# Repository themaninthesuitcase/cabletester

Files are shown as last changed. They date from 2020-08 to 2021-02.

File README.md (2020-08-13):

Arduino 10/16 pin Eurorack IDC Power Cable Tester
=================================================

Forked from [https://github.com/tomarus/cabletester](https://github.com/tomarus/cabletester) with slight modifications to circuit and software (mainly order of connections), and with PCB layout added.

* It only tests (max) 8 wires because of how they're wired in eurorack.
* It can detect shorted cables or faulty/unconnected wires.

This project uses a 128x64 OLED I2C display module with four interface pins: GND, +12V, SCL, and SDA. It is a monochrome display although it is available in a version with a yellow and blue overlay as seen in the photos. Note that the OLED pinout sometimes is GND-VCC-SCL-SDA and sometimes VCC-GND-SCL-SDA. The initial run of boards assumed the latter pinout; the present design has footprints for both.

These modules are available from the "usual suspects" on Amazon, eBay, AliExpress, etc. I have one of [these](https://www.amazon.com/gp/product/B072Q2X2LL) (GND-VCC-SCL-SDA) and one of [these](https://www.amazon.com/gp/product/B07FK8GB8T) (VCC-GND-SCL-SDA). They do *not* seem to be available from any established vendors like Mouser, DigiKey, Tayda, Adafruit, or SparkFun. Please make sure you have a source for the display before proceeding with this project! 

Code uses these libraries:

* https://github.com/adafruit/Adafruit_SSD1306
* https://github.com/adafruit/Adafruit-GFX-Library

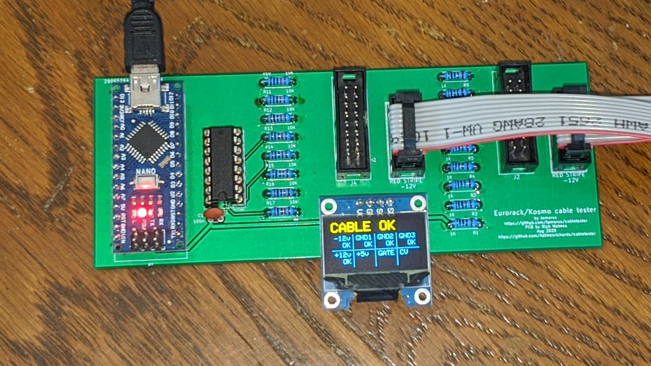
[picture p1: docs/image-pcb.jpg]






# Schematics

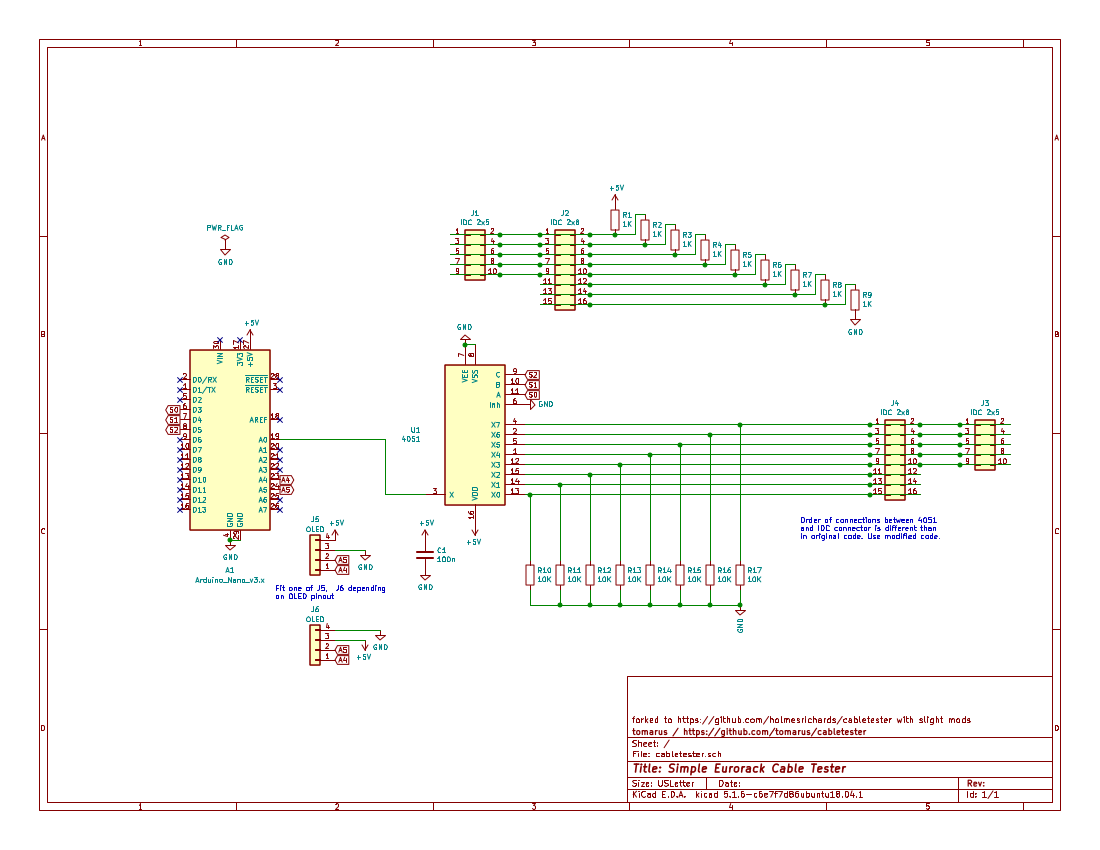
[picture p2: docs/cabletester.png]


# PCB

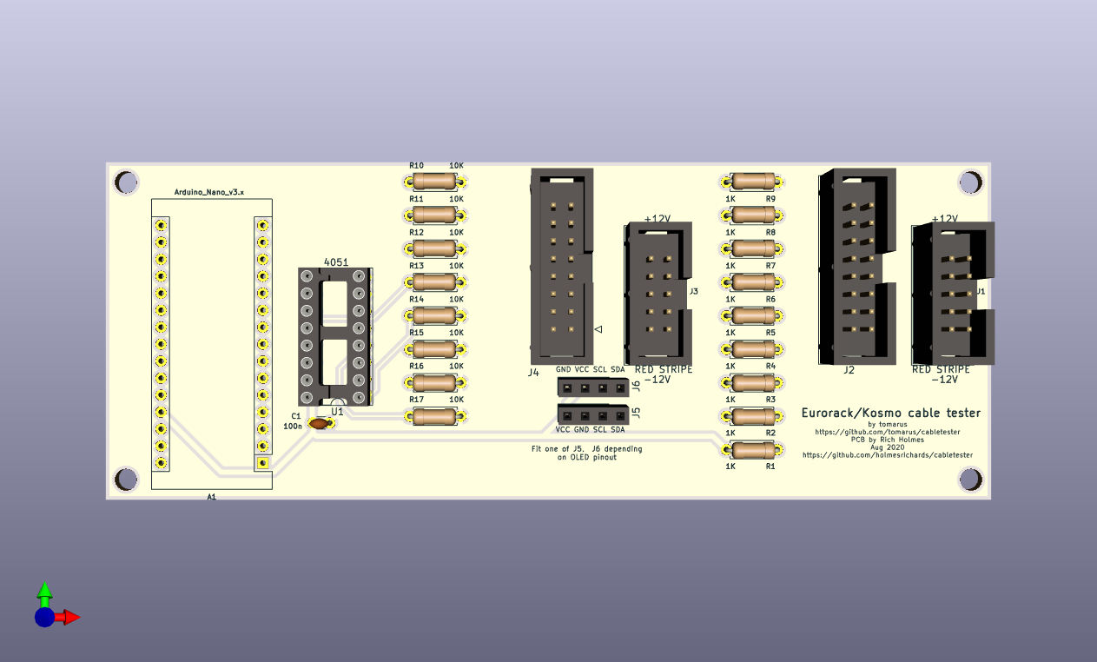
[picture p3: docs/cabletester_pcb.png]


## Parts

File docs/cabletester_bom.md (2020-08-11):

# cabletester BOM

Tue 11 Aug 2020 08:37:09 AM EDT

Generated from schematic by Eeschema 5.1.6-c6e7f7d~86~ubuntu18.04.1

**Component Count:** 26

| Value | Qty | Part | Description | Vendor |
| ----- | --- | ---- | --- | --- |
| A1 | 1 | Arduino_Nano_v3.x | Arduino Nano v3.x | Tayda A-2864 |
| C1 | 1 | 100 nF | Unpolarized capacitor | Tayda A-564 |
| J1, J3 | 2 | IDC 2x5 | Eurorack style 10 pin power header | Tayda A-2939 |
| J2, J4 | 2 | IDC 2x8 | Eurorack style 16 pin power header | Tayda A-2956 |
| J5, J6 | 1 | 4 pin header | 4 pin female 2.54 mm header (fit in one of two locations) | Tayda A-1303 |
| R1, R2, R3, R4, R5, R6, R7, R8, R9 | 9 | 1K | Resistor | Tayda A-2200 |
| R10, R11, R12, R13, R14, R15, R16, R17 | 8 | 10K | Resistor | Tayda A-2203 |
| U1 | 1 | 4051 | Analog Multiplexer 8 to 1 | Tayda A-026 |
| – | 1 | – | 128x64 monochrome I2C OLED module | eBay, AliExpress... |

See [README](../README.md) for notes on OLED module.

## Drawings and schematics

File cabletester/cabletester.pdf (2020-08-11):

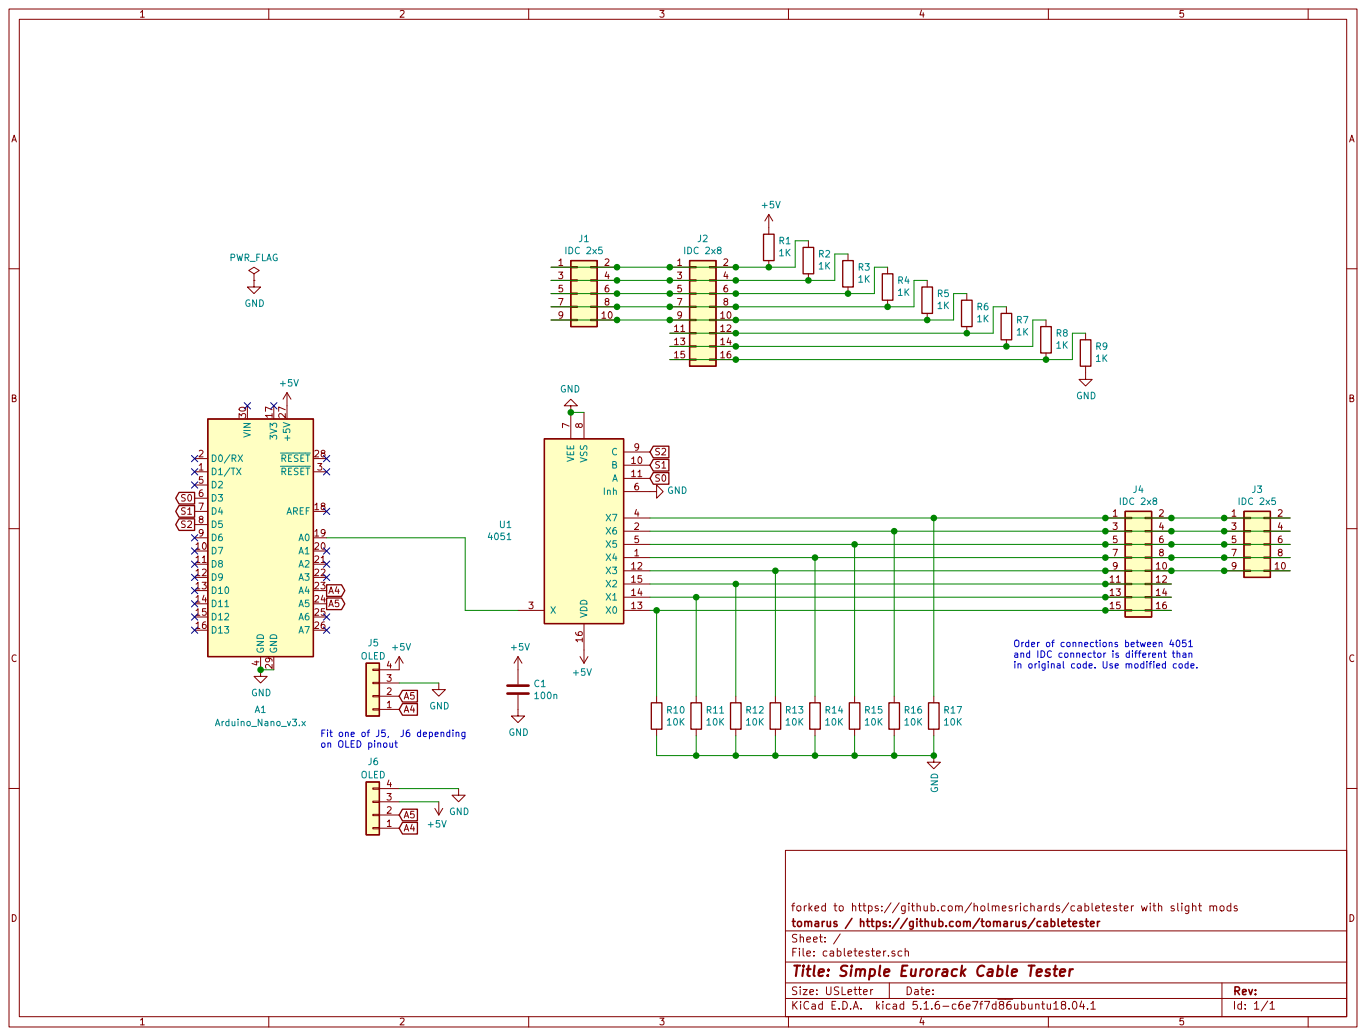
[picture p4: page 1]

and IDC connector is different than
in original code. Use modified code.

Fit one of J5, J6 depending
on OLED pinout

forked to https://github.com/holmesrichards/cabletester with slight mods
Id: 1/1 Title: Simple Eurorack Cable Tester File: cabletester.sch Sheet: / tomarus / https://github.com/tomarus/cabletester

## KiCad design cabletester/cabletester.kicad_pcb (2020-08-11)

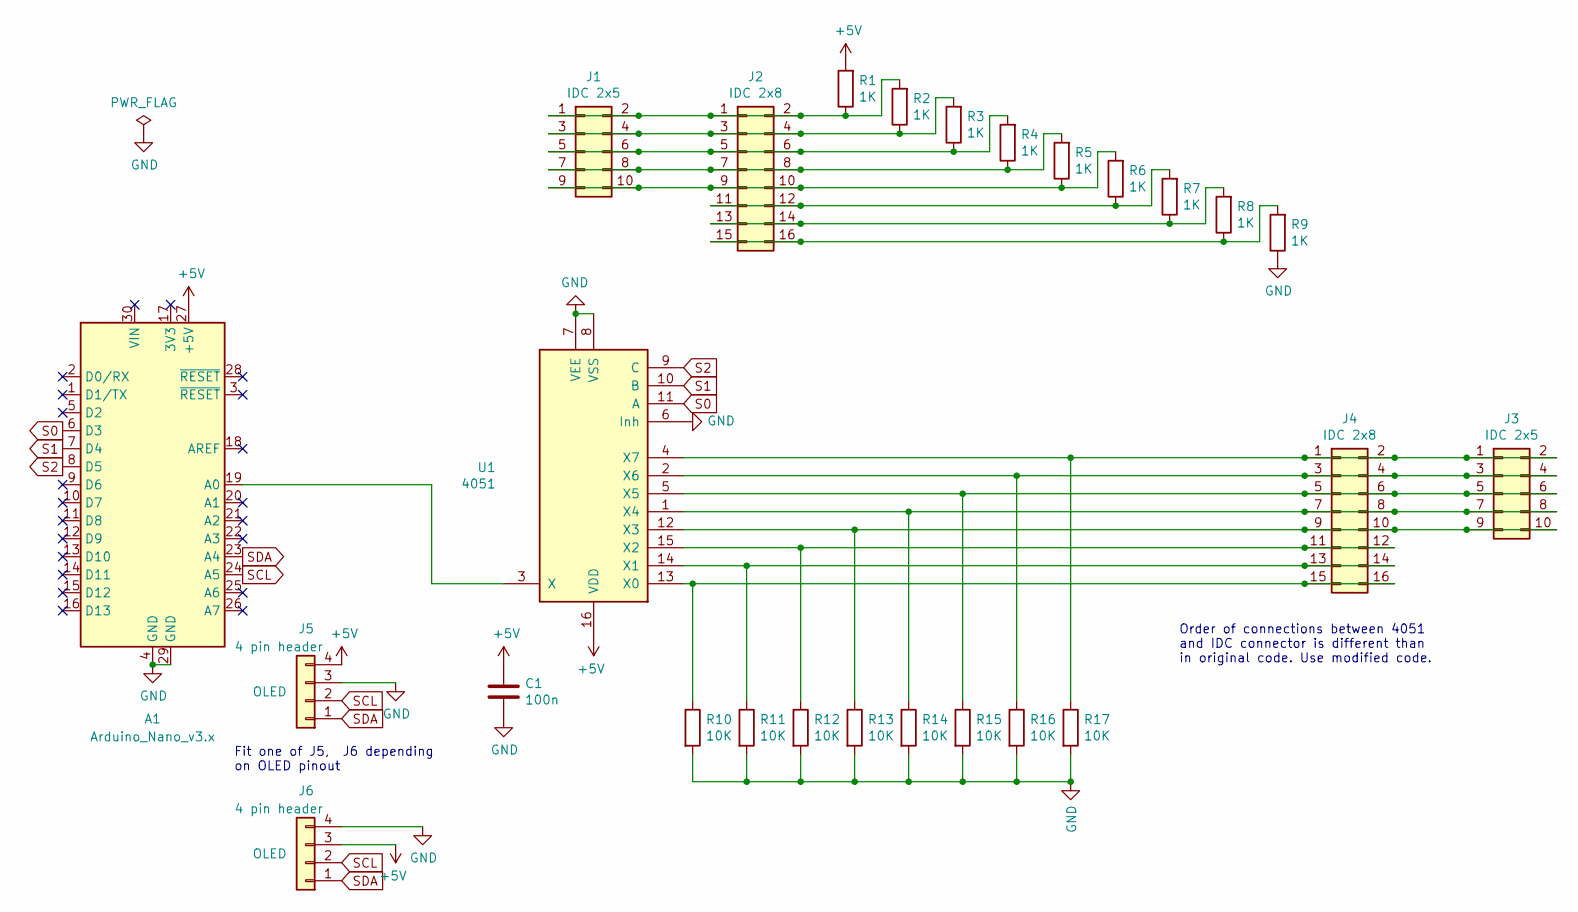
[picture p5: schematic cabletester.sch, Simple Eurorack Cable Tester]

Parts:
A1: Arduino_Nano_v3.x; Arduino_Nano
C1: 100n; C_Disc_D3.0mm_W1.6mm_P2.50mm
J1, J3: IDC 2x5; Power_Header
J2, J4: IDC 2x8; IDC-Header_2x08_P2.54mm_Vertical
J5, J6: 4 pin header; PinSocket_1x04_P2.54mm_Vertical
R1, R2, R3, R4, R5, R6, R7, R8, R9: 1K; R_Axial_DIN0207_L6.3mm_D2.5mm_P7.62mm_Horizontal
R10, R11, R12, R13, R14, R15, R16, R17: 10K; R_Axial_DIN0207_L6.3mm_D2.5mm_P7.62mm_Horizontal
U1: 4051; DIP-16_W7.62mm_Socket_LongPads

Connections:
+5V: A1.27 (+5V), C1.1, J5.4, J6.3, R1.2, U1.16 (VDD)
A4: A1.23 (A4), J5.1, J6.1
A5: A1.24 (A5), J5.2, J6.2
GND: A1.4 (GND), A1.29 (GND), C1.2, J5.3, J6.4, R9.1, R10.2, R11.2, R12.2, R13.2, R14.2, R15.2, R16.2, R17.2, U1.6 (Inh), U1.7 (VEE), U1.8 (VSS)
unnamed: A1.19 (A0), U1.3 (X)
unnamed: J1.1, J1.2, J2.1, J2.2, R1.1, R2.2
unnamed: J1.3, J1.4, J2.3, J2.4, R2.1, R3.2
unnamed: J1.5, J1.6, J2.5, J2.6, R3.1, R4.2
unnamed: J1.7, J1.8, J2.7, J2.8, R4.1, R5.2
unnamed: J1.9, J1.10, J2.9, J2.10, R5.1, R6.2
unnamed: J2.11, J2.12, R6.1, R7.2
unnamed: J2.13, J2.14, R7.1, R8.2
unnamed: J2.15, J2.16, R8.1, R9.2
unnamed: J3.1, J3.2, J4.1, J4.2, R17.1, U1.4 (X7)
unnamed: J3.3, J3.4, J4.3, J4.4, R16.1, U1.2 (X6)
unnamed: J3.5, J3.6, J4.5, J4.6, R15.1, U1.5 (X5)
unnamed: J3.7, J3.8, J4.7, J4.8, R14.1, U1.1 (X4)
unnamed: J3.9, J3.10, J4.9, J4.10, R13.1, U1.12 (X3)
unnamed: J4.11, J4.12, R12.1, U1.15 (X2)
unnamed: J4.13, J4.14, R11.1, U1.14 (X1)
unnamed: J4.15, J4.16, R10.1, U1.13 (X0)
S0: A1.6 (D3), U1.11 (A)
S1: A1.7 (D4), U1.10 (B)
S2: A1.8 (D5), U1.9 (C)

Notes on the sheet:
Order of connections between 4051 and IDC connector is different than in original code. Use modified code.
Fit one of J5, J6 depending on OLED pinout

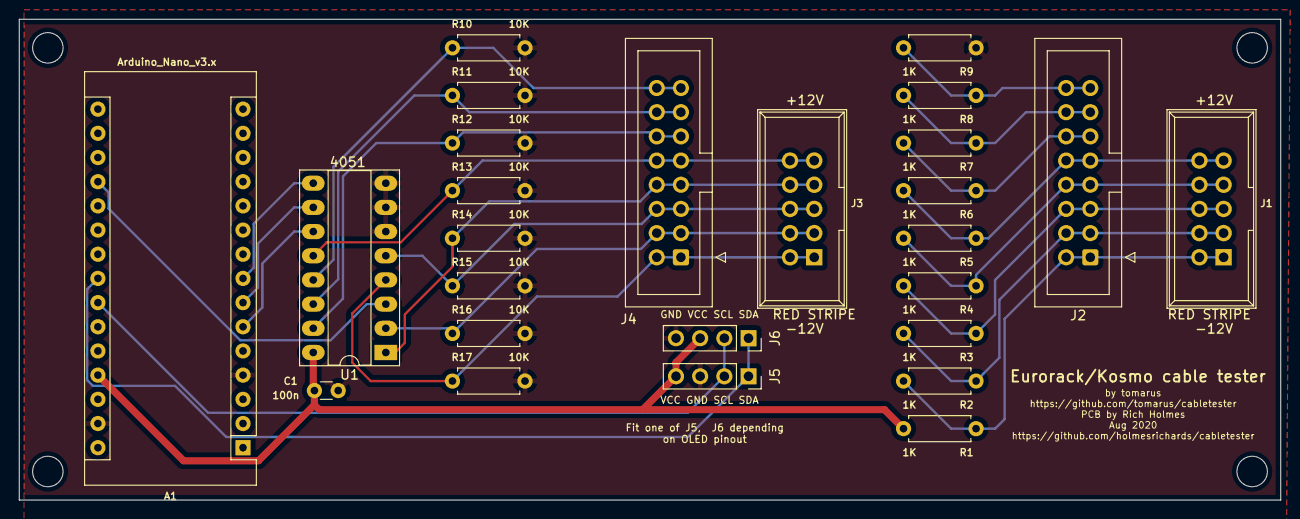
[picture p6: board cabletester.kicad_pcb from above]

Board: 2 copper layers, 132.5 x 50.5 mm, 26 parts (0 on the bottom side), 24 nets.

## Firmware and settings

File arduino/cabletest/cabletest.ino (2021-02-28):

#include <Adafruit_SSD1306.h>

#define OLED_ADDR 0x3C
Adafruit_SSD1306 display(128, 64);

#define PIN_4051_S0 3
#define PIN_4051_S1 4
#define PIN_4051_S2 5
#define PIN_4051_A A0

// set DEBUG to true to display raw ADC values instead of just "OK"
const bool DEBUG = false;

const char *labels[] = {
	"-12v", "GND1", "GND2", "GND3", "+12v", "+5v", "GATE", "CV"};

// map 4051 input pins to display order
// must match label order
// see read_values()
// this is really hacky and ugly and depends on your wiring
// Index is MUX pin, value is IDC pin (0-7)
const int order[] = {
	7, // cv
	6, // gate
	5, // +5v
	4, // +12v
	3, // gnd3
	2, // gnd2
	1, // gnd1
	0  // -12v
};

// allow some fluctuation on our ADC
const int margin = 20;

// expected values (+/- margin)
// might need some tweaking
// this is really hacky too
const int expect[] = {
	746, 544, 395, 286, 204, 130, 80, 35};

const int open_threshold = 15;

int cable_status = 0;
int prev_status = -1;
const char *statuses[] = {
	"CABLE OK",
	"NO CABLE",
	"SHORTED",
	"BAD CABLE"};

int values[] = {1, 1, 1, 1, 1, 1, 1, 1};
int newvalues[] = {0, 0, 0, 0, 0, 0, 0, 0};

void setup()
{
  Serial.begin(9600);
  Serial.println("beg setup");

  display.begin(SSD1306_SWITCHCAPVCC, OLED_ADDR); 
  display.clearDisplay();

  display.setTextColor(WHITE, BLACK);
  display.setTextSize(1);
  display.setCursor (0, 32);
  display.println("clear");
  display.display();
	
  Serial.println("end setup");
}
void setupx()
{
	pinMode(PIN_4051_S0, OUTPUT);
	pinMode(PIN_4051_S1, OUTPUT);
	pinMode(PIN_4051_S2, OUTPUT);

	display.begin(SSD1306_SWITCHCAPVCC, OLED_ADDR);
	display.clearDisplay();

	draw_status();

	display.setTextColor(WHITE, BLACK);
	display.setTextSize(1);
	for (int i = 0; i < 8; i++)
	{
		int x = (i & 3) * 32;
		int y = i < 4 ? 18 : 42;
		display.setCursor(x + 4, y);
		display.print(labels[i]);
	}

	hdotline(39);
	vdotline(31);
	vdotline(63);
	vdotline(95);
	display.display();

}

void loop()
{
  /* 	read_values(); */
  /* 	check_status(); */

  /* 	display.setTextSize(1); */
  /* 	for (int i = 0; i < 8; i++) */
  /* 	{ */
  /* 		draw_value(i); */
  /* } */
  /* 	draw_status(); */
  /* 	display.display(); */
}

void hdotline(int y)
{
	for (int i = 1; i < display.width(); i += 2)
	{
		display.drawPixel(i, y, SSD1306_WHITE);
	}
}

void vdotline(int x)
{
	for (int i = 17; i < display.height(); i += 2)
	{
		display.drawPixel(x, i, SSD1306_WHITE);
	}
}

// inmargin checks if value is within the expected range
bool inmargin(const int value, const int expect)
{
	return value > expect - margin && value < expect + margin;
}

// check_status checks for shorts, nr of unconnected wires, etc
void check_status()
{
	int allok = 0;
	int nc = 0;
	int shrt = 0;

	for (int i = 0; i < 8; i++)
	{
		int prev = i == 0 ? 7 : i - 1;
		int next = i == 7 ? 0 : i + 1;

		if (values[i] < open_threshold)
		{
			nc++;
		}
		else if (inmargin(values[i], values[prev]) || inmargin(values[i], values[next]))
		{
			shrt++;
		}
		else if (inmargin(values[i], expect[i]))
		{
			allok++;
		}
	}

	// advanced AI to decide on the cable status
	if (allok == 8 || (allok == 5 && nc == 3))
	{
		// everything should be ok
		cable_status = 0;
	}
	else if (nc == 8)
	{
		// no cable
		cable_status = 1;
	}
	else if (shrt > 0)
	{
		// shorted somewhere
		cable_status = 2;
	}
	else
	{
		// otherwise a bad cable
		cable_status = 3;
	}

}

// draw_status renders the global status on top of the screen
void draw_status()
{
	if (cable_status != prev_status)
	{
		prev_status = cable_status;
		display.setTextSize(2);
		display.setCursor(0, 0);
		display.print("          ");
		display.setCursor(0, 0);
		display.print(statuses[cable_status]);
	}
}

// align_value right aligns a 4-digit number for a 6px font width.
void align_value(int x, int y, int v)
{
	int off = v < 10 ? 18 : v < 100 ? 12 : v < 1000 ? 6 : 0;
	display.setCursor(x + off, y);
	display.print(v);
}

// draw_value renders one of the eight display boxes.
void draw_value(const int n)
{
	if (newvalues[n] == values[n])
		// return early, do nothing if the value isn't changed
		return;

	values[n] = newvalues[n];
	int v = values[n];

	int x = (n & 3) * 32;
	int y = n < 4 ? 28 : 52;
	display.setCursor(x, y);
	display.print("     ");

	if (v < 5)
	{
		// return early, 0 volt, unconnected wire,
		// display nothing for unconnected wires
		return;
	}

	int prev = n == 0 ? 7 : n - 1;
	int next = n == 7 ? 0 : n + 1;
	if (values[n] >= open_threshold && (inmargin(values[n], values[prev]) || inmargin(values[n], values[next])))
	{
		// If our next or previous value is the same (+/- margin)
		// there is probably a short circuit.
		display.setCursor(x + 1, y);
		display.print("SHORT");
	}
	else if (inmargin(values[n], expect[n]))
	{
		// Measurements are within limits
		// Display OK or it's raw value
		if (DEBUG)
		{
			align_value(x + 4, y, v);
		}
		else
		{
			display.setCursor(x + 16, y);
			display.print("OK");
		}
	}
	else if (values[n] >= open_threshold)
	{
		// Display raw ADC value if out of limits.
		align_value(x + 4, y, v);
	}
}

// myAnalogRead reads the analog input twice
// to stabilize the ADC input before returning
// a value.
int myAnalogRead(int pin)
{
	analogRead(pin);
	return analogRead(pin);
}

// read_values updates all values from the 4051 mux.
void read_values()
{
	for (int i = 0; i < 8; i++)
	{
		digitalWrite(PIN_4051_S0, i & 1);
		digitalWrite(PIN_4051_S1, i & 2);
		digitalWrite(PIN_4051_S2, i & 4);
		newvalues[order[i]] = myAnalogRead(PIN_4051_A);
	}
}

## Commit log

2020-08-02 Schematic cleanup
    [cabletester.kicad_pcb, cabletester.sch]
2020-08-02 First version after fork, schematic cleanup and PCB
    [cabletester.kicad_pcb, cabletester.sch]
2020-08-03 labels to globals, page settings
    [cabletester.sch]
2020-08-05 Gerbers, update PCB, updated README
    [cabletester-B_Cu.gbr, cabletester-B_Mask.gbr, cabletester-B_Paste.gbr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]
2020-08-11 Add 2nd header for alternate OLED pinout
    [cabletester.kicad_pcb, cabletester.sch]
2020-08-11 README update for OLED info, show PCB; change label on PCB
    [cabletester.kicad_pcb]
2020-08-11 BOM; change header label
    [cabletester.kicad_pcb, cabletester.sch]
2020-08-11 Clearer labels; software revisions to match my woring
    [cabletester.sch]
2020-08-11 added mounting holes, new Gerbers
    [cabletester-B_Cu.gbr, cabletester-B_Mask.gbr, cabletester-B_Paste.gbr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]
2020-08-13 Display sources; PCB photo
2021-01-02 Footprints updated
2021-02-19 Footprint update
